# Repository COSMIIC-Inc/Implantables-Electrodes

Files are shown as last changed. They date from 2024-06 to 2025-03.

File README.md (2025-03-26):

# Implantables-Electrodes Read Me

## Contents
This repository is home to the 3D CAD design files of the electrodes in the COSMIIC System.
Further documentation is available at **[docs.cosmiic.org/Implantables/Electrodes](https://docs.cosmiic.org/Implantables/Electrodes)**

## Licensing
Hardware-related files are licensed to open source users by COSMIIC under the CERN Open Hardware License - Permissive - v2 (CERN-OHL-P-2.0). Refer to the **[license text](https://ohwr.org/cern_ohl_p_v2.txt)** (also embedded in the repository as **LICENSE.txt**) and **[user guide](https://ohwr.org/project/cernohl/-/wikis/uploads/8a6b5d01f71c207c49493e4d114d61e6/cern_ohl_p_v2_howto.pdf)** to understand your permissions.

Hardware-related files includes, but is not limited to...

- Mechanical Design
    - 3D CAD Files (parts and assemblies, multiple file types)
    - Mechanical Drawings (parts and assemblies, mulitple file types)
- PCB Design
    - Fabrication (Gerber and Drill files)
    - Assembly (Pick and Place, BOM)
    - Archive (Schematics, multiple file types)

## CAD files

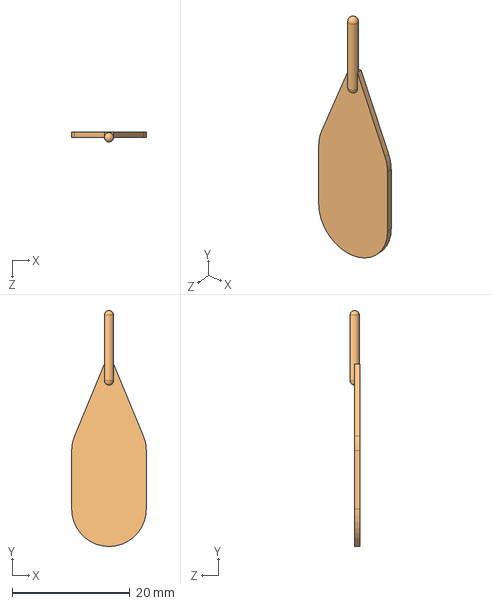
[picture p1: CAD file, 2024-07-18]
Mechanical Design CAD Files/Epimysial MES Electrode Cable/SolidWorks Native Files/NNP-DWG-145-008-000 SA, EPI, MES, Electrode.SLDASM
12.7 x 40.1 x 1.68 mm
NNP-DWG-140-015-000 Electrode, EPI, MES, Silicone Molding Blank
NNP-DWG-140-014-000 Electrode, EPI, Disk x 2

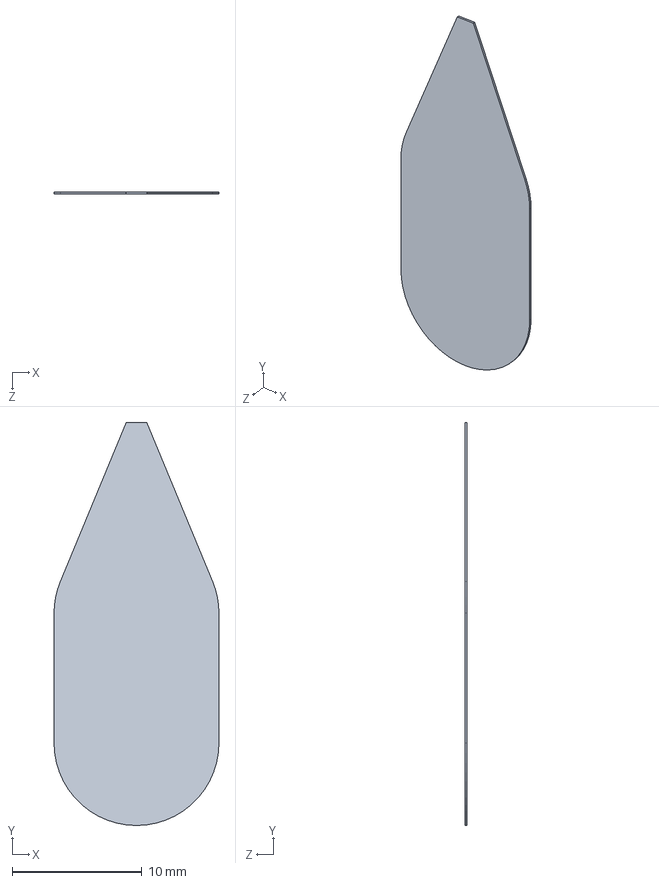
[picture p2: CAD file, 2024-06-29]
Mechanical Design CAD Files/Epimysial MES Electrode Cable/STEP Files/NNP-DWG-140-016-000 Electrode, EPI, MES, Reinforcing Mesh.STEP
12.7 x 31.0 x 0.178 mm

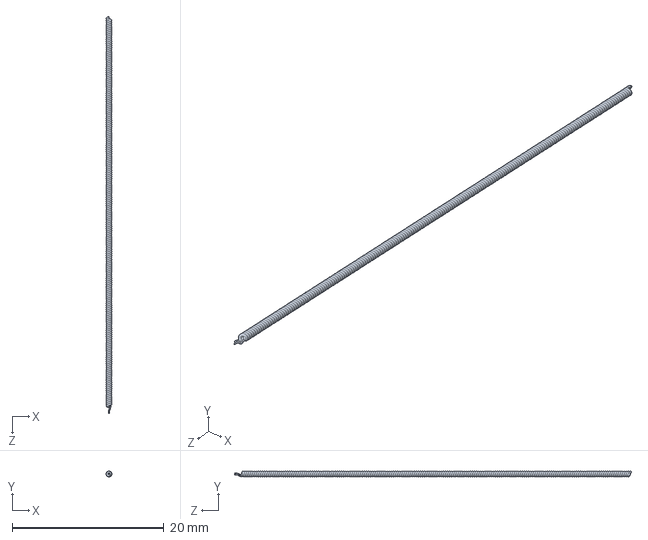
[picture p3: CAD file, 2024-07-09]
Mechanical Design CAD Files/IM Stim Electrode Cable/SolidWorks Native Files/NNP-DWG-140-011-001 Filar, SS, Red-Clear.SLDPRT
0.753 x 0.753 x 52.3 mm

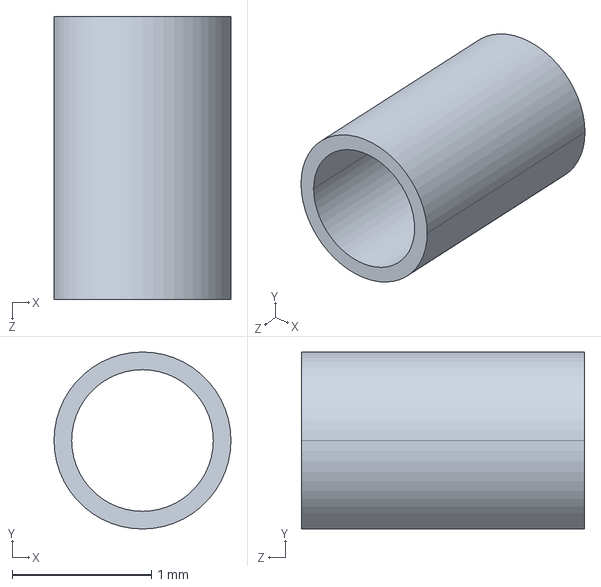
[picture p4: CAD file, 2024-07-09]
Mechanical Design CAD Files/IM Stim Electrode Cable/STEP Files/NNP-DWG-140-019-002 Electrode, IM, Stim, Coil.STEP
1.27 x 1.27 x 2.03 mm

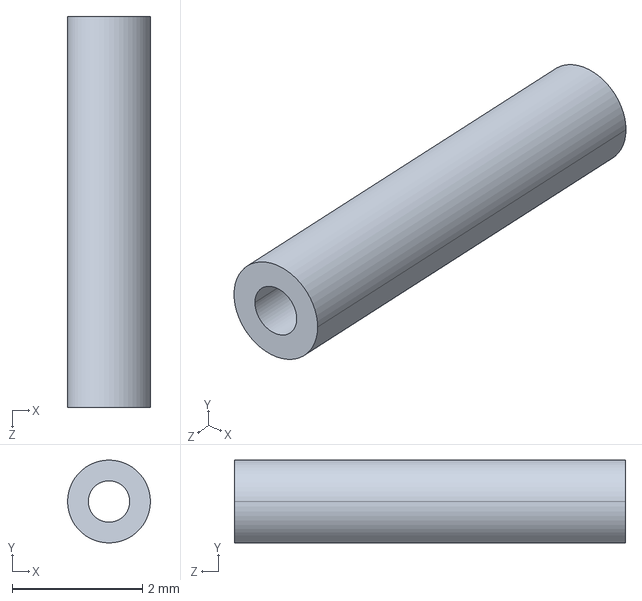
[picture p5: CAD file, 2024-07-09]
Mechanical Design CAD Files/IM-MES Electrode Cable/STEP Files/NNP-DWG-140-018-000 Electrode, IM, Silicone Tubing Spacer.STEP
1.27 x 1.27 x 5.99 mm

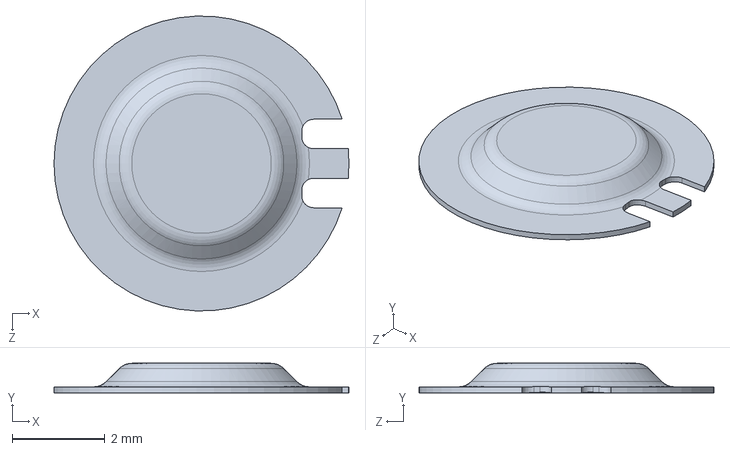
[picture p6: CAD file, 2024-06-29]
Mechanical Design CAD Files/Epimysial MES Electrode Cable/SolidWorks Native Files/NNP-DWG-140-014-000 Electrode, EPI, Disk.SLDPRT
6.35 x 0.635 x 6.35 mm

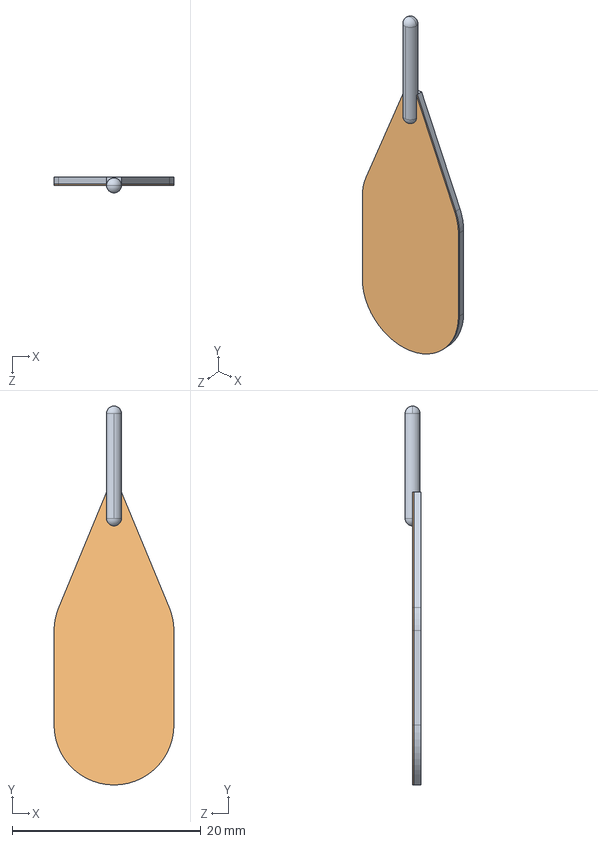
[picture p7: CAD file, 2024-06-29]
Mechanical Design CAD Files/Epimysial MES Electrode Cable/STEP Files/NNP-DWG-145-008-000 SA, EPI, MES, Electrode.STEP
12.7 x 40.1 x 1.68 mm
NNP-DWG-140-015-000 Electrode, EPI, MES, Silicone Molding Blank
NNP-DWG-140-016-000 Electrode, EPI, MES, Reinforcing Mesh
NNP-DWG-140-014-000 Electrode, EPI, Disk x 2

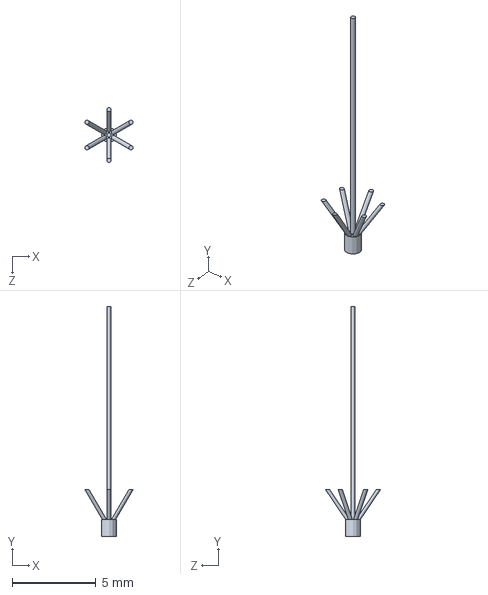
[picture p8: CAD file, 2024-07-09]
Mechanical Design CAD Files/IM Stim Electrode Cable/SolidWorks Native Files/NNP-DWG-140-013-002 Electrode, IM, Stim, Prolene Barb.SLDPRT
2.87 x 13.7 x 3.28 mm

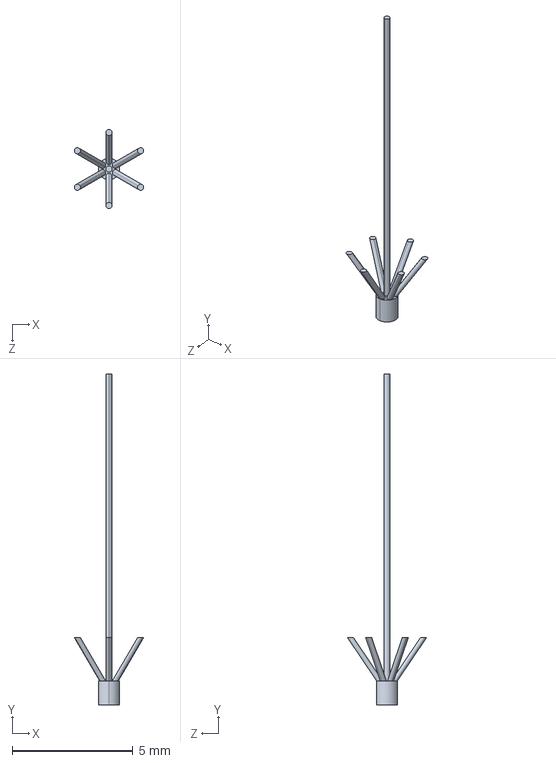
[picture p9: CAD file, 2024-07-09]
Mechanical Design CAD Files/IM Stim Electrode Cable/STEP Files/NNP-DWG-140-013-002 Electrode, IM, Stim, Prolene Barb.STEP
2.87 x 13.7 x 3.28 mm

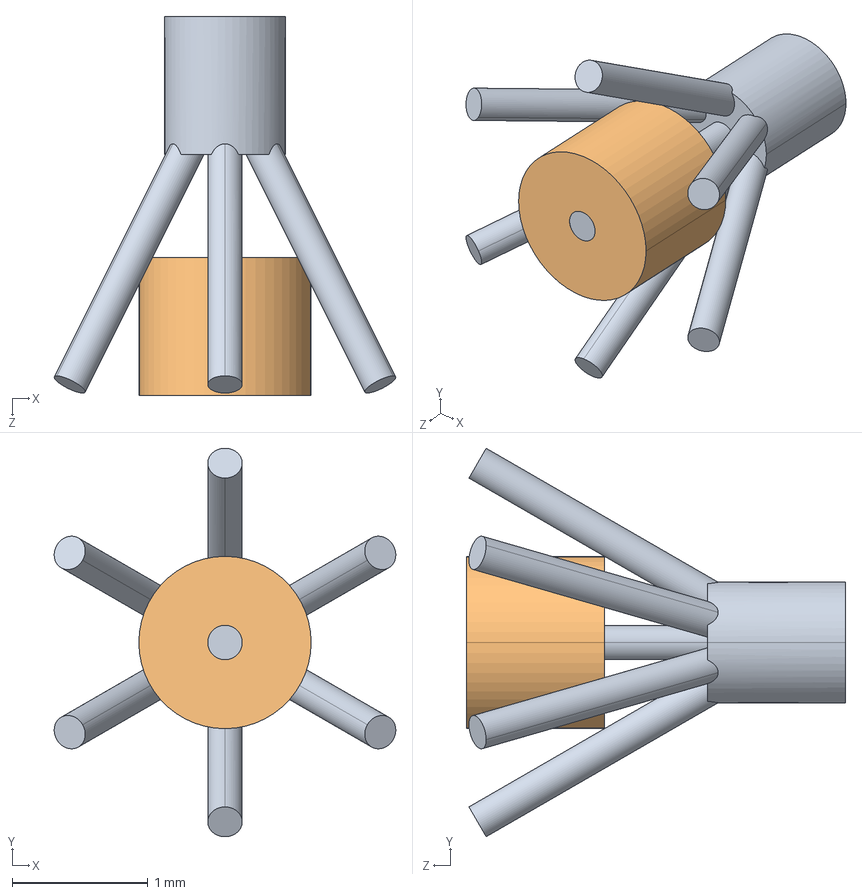
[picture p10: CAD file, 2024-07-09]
Mechanical Design CAD Files/IM-MES Electrode Cable/STEP Files/NNP-DWG-145-010-000 SA, Electrode, IM, Barb Tip.STEP
2.52 x 2.86 x 2.79 mm
NNP-DWG-140-013-000 Electrode, IM, Prolene Barb
NNP-DWG-140-017-000 Electrode, IM, Silicone Tube Extension

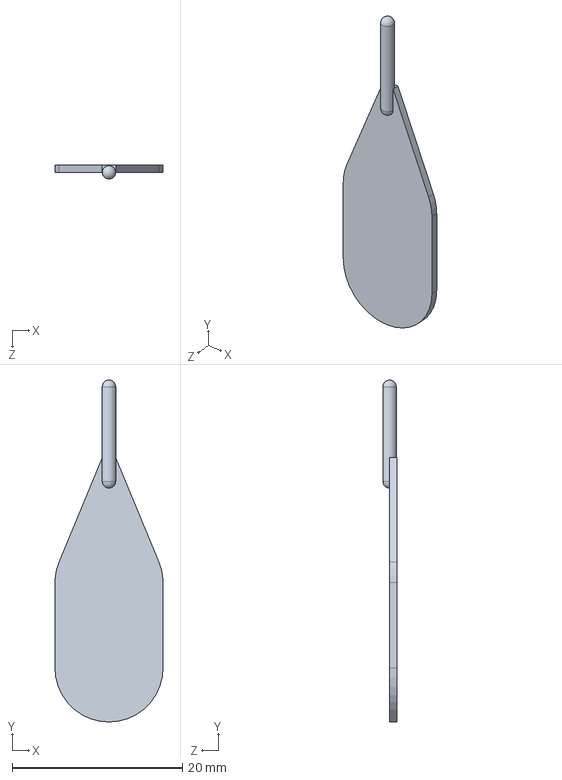
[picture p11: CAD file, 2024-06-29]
Mechanical Design CAD Files/Epimysial MES Electrode Cable/SolidWorks Native Files/NNP-DWG-140-015-000 Electrode, EPI, MES, Silicone Molding Blank.SLDPRT
12.7 x 40.1 x 1.68 mm

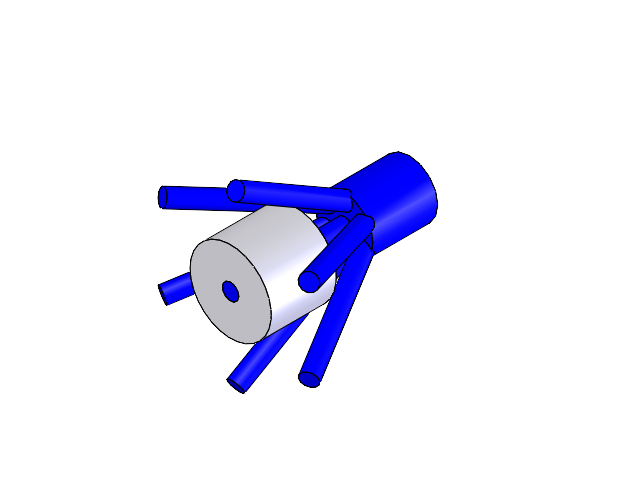
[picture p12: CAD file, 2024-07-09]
Mechanical Design CAD Files/IM-MES Electrode Cable/SolidWorks Native Files/NNP-DWG-145-010-000 SA, Electrode, IM, Barb Tip.SLDASM
NNP-DWG-140-013-001 Electrode, IM, MES, Prolene Barb
NNP-DWG-140-017-000 Electrode, IM, Silicone Tube Extension

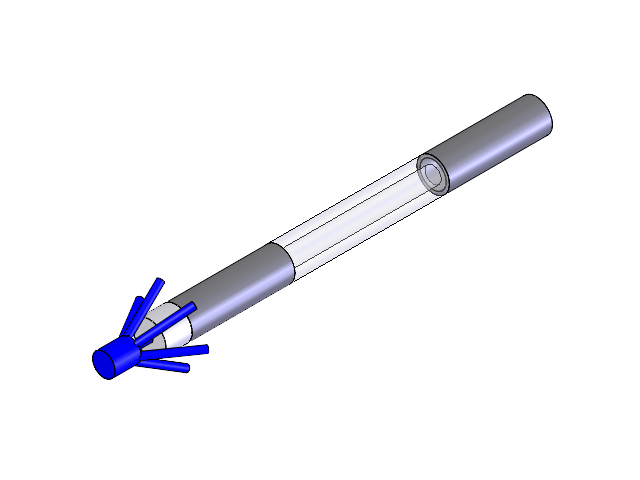
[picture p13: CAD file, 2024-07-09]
Mechanical Design CAD Files/IM-MES Electrode Cable/SolidWorks Native Files/NNP-DWG-145-011-000 SA, Electrode, IM, MES.SLDASM
NNP-DWG-140-019-001 Electrode, IM, MES, Coil x 2
NNP-DWG-140-013-001 Electrode, IM, MES, Prolene Barb
NNP-DWG-140-017-000 Electrode, IM, Silicone Tube Extension
NNP-DWG-140-018-000 Electrode, IM, Silicone Tubing Spacer

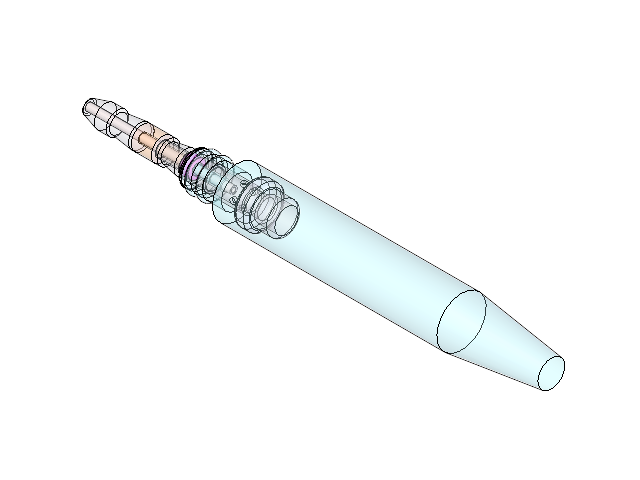
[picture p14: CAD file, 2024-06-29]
Mechanical Design CAD Files/Epimysial MES Electrode Cable/STEP Files/NNP-DWG-145-001-000 Interconnect.SLDASM
NNP-DWG-140-004-000 Interconnect, Front-Rear Insulator
NNP-DWG-140-002-001 Interconnect, Rear Contact, SS
NNP-DWG-140-007-001 Interconnect, Front Weld Sleeve, SS
NNP-DWG-140-008-001 Interconnect, Crimp Weld Reducer, SS
NNP-DWG-140-009-000 Interconnect, Silicone Over Mold
NNP-DWG-140-003-001 Interconnect, NNP Center Conductor, SS
NNP-DWG-140-006-000 Interconnect, Washer
NNP-DWG-140-005-001 Interconnect, Strain Relief, SS
NNP-DWG-140-001-001 Interconnect, Front Contact, SS

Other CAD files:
Mechanical Design CAD Files/IM-MES Electrode Cable/SolidWorks Native Files/NNP-DWG-145-001-000 Interconnect.SLDASM
Mechanical Design CAD Files/IM Stim Electrode Cable/SolidWorks Native Files/NNP-DWG-145-012-000 SA, Electrode, IM, Stim.SLDASM
Mechanical Design CAD Files/IM Stim Electrode Cable/SolidWorks Native Files/NNP-DWG-145-001-000 Interconnect.SLDASM
Mechanical Design CAD Files/IM-MES Electrode Cable/SolidWorks Native Files/NNP-DWG-145-007-003 SA, Cable Body, Insulated SS Filars, Green-Clear.SLDASM
Mechanical Design CAD Files/Epimysial MES Electrode Cable/STEP Files/NNP-DWG-140-014-000 Electrode, EPI, Disk.STEP
Mechanical Design CAD Files/Epimysial MES Electrode Cable/STEP Files/NNP-DWG-140-015-000 Electrode, EPI, MES, Silicone Molding Blank.STEP
Mechanical Design CAD Files/Epimysial MES Electrode Cable/SolidWorks Native Files/NNP-DWG-140-014-000 Electrode, EPI, Disk.SLDDRW
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

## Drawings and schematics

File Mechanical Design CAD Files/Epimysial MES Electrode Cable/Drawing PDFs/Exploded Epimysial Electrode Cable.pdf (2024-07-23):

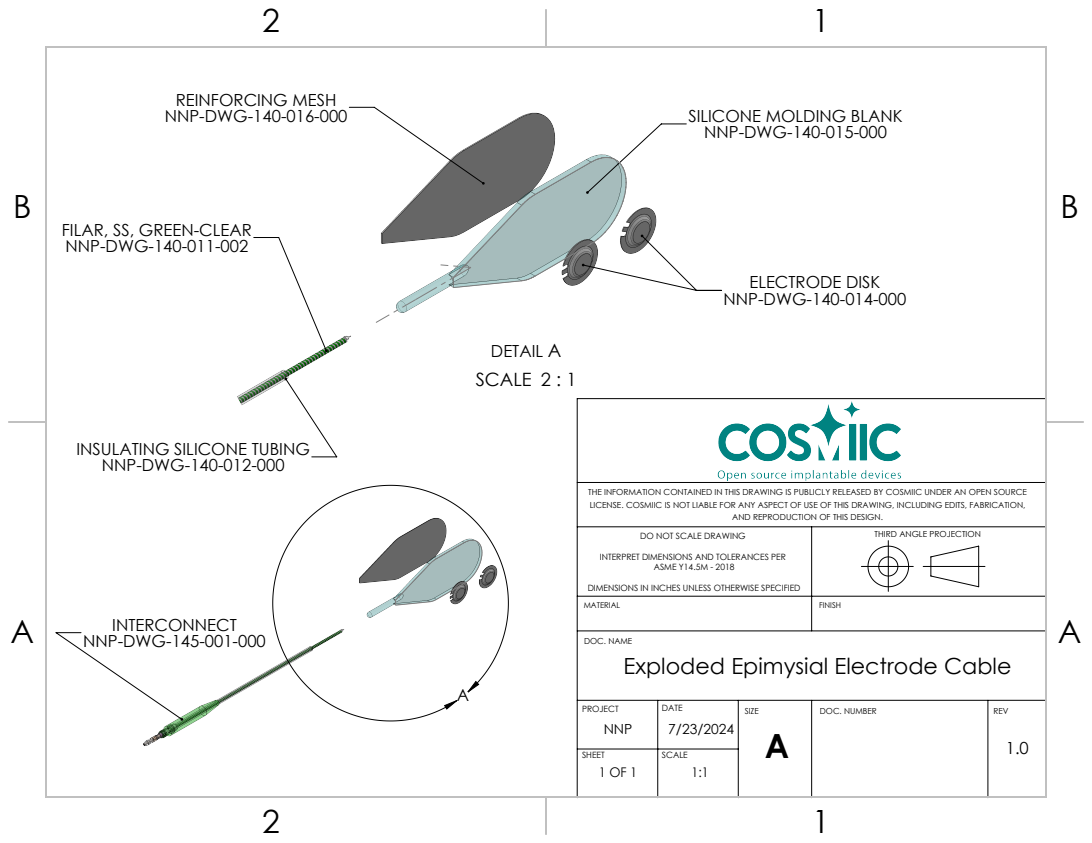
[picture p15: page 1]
DETAIL A SCALE 2 : 1; ELECTRODE DISK; REINFORCING MESH; ASME Y14.5M - 2018; DOC. NAME; DOC. NUMBER; REV

SILICONE MOLDING BLANK
NNP-DWG-140-015-000

FILAR, SS, GREEN-CLEAR
NNP-DWG-140-011-002

INSULATING SILICONE TUBING
NNP-DWG-140-012-000

THE INFORMATION CONTAINED IN THIS DRAWING IS PUBLICLY RELEASED BY COSMIIC UNDER AN OPEN SOURCE
LICENSE. COSMIIC IS NOT LIABLE FOR ANY ASPECT OF USE OF THIS DRAWING, INCLUDING EDITS, FABRICATION,

AND REPRODUCTION OF THIS DESIGN.

DO NOT SCALE DRAWING

THIRD ANGLE PROJECTION

INTERPRET DIMENSIONS AND TOLERANCES PER

DIMENSIONS IN INCHES UNLESS OTHERWISE SPECIFIED
Exploded Epimysial Electrode Cable

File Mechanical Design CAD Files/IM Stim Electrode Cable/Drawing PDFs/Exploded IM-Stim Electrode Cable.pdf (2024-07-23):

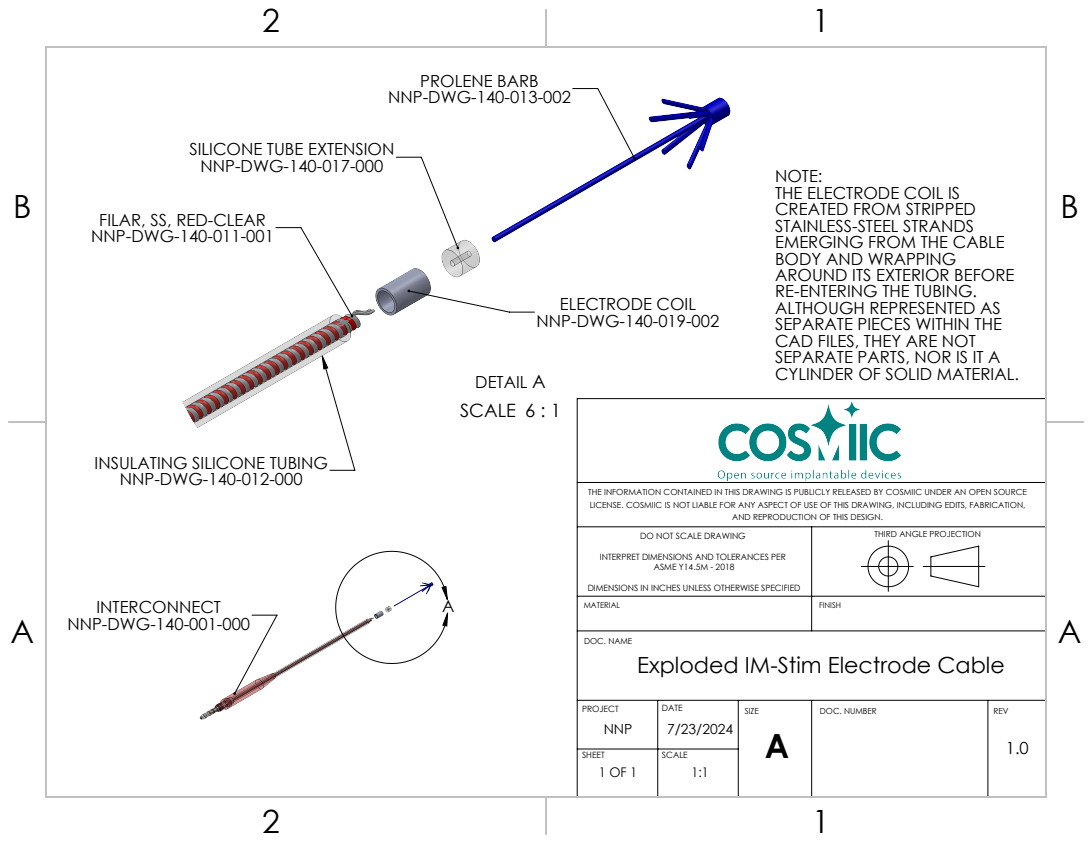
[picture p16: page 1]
DETAIL A SCALE 6 : 1; PROLENE BARB; ELECTRODE COIL; ASME Y14.5M - 2018; DOC. NAME; DOC. NUMBER; REV

SILICONE TUBE EXTENSION
NNP-DWG-140-017-000

NOTE:
THE ELECTRODE COIL IS
CREATED FROM STRIPPED
STAINLESS-STEEL STRANDS
EMERGING FROM THE CABLE
BODY AND WRAPPING
AROUND ITS EXTERIOR BEFORE
RE-ENTERING THE TUBING.
ALTHOUGH REPRESENTED AS
SEPARATE PIECES WITHIN THE
CAD FILES, THEY ARE NOT
SEPARATE PARTS, NOR IS IT A
CYLINDER OF SOLID MATERIAL.

FILAR, SS, RED-CLEAR
NNP-DWG-140-011-001

INSULATING SILICONE TUBING
NNP-DWG-140-012-000

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

AND REPRODUCTION OF THIS DESIGN.

DO NOT SCALE DRAWING

THIRD ANGLE PROJECTION

INTERPRET DIMENSIONS AND TOLERANCES PER

DIMENSIONS IN INCHES UNLESS OTHERWISE SPECIFIED
Exploded IM-Stim Electrode Cable

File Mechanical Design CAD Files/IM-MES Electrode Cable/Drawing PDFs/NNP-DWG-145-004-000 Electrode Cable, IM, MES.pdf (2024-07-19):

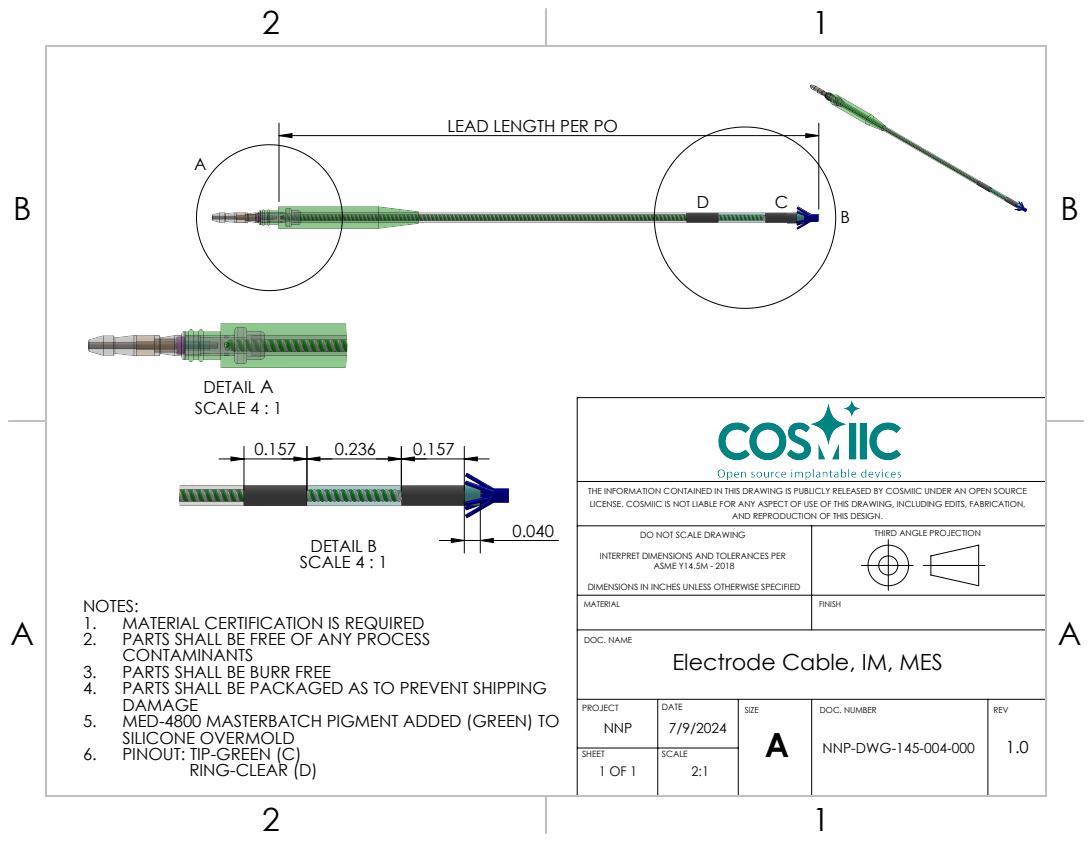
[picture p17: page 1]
DETAIL A SCALE 4 : 1; DETAIL B SCALE 4 : 1; RING-CLEAR (D); ASME Y14.5M - 2018; DOC. NAME; DOC. NUMBER; REV

LEAD LENGTH PER PO

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

AND REPRODUCTION OF THIS DESIGN.

DO NOT SCALE DRAWING

THIRD ANGLE PROJECTION

INTERPRET DIMENSIONS AND TOLERANCES PER

DIMENSIONS IN INCHES UNLESS OTHERWISE SPECIFIED
Electrode Cable, IM, MES

NOTES:
1. MATERIAL CERTIFICATION IS REQUIRED

2. PARTS SHALL BE FREE OF ANY PROCESS
CONTAMINANTS
3. PARTS SHALL BE BURR FREE
4. PARTS SHALL BE PACKAGED AS TO PREVENT SHIPPING
DAMAGE
5. MED-4800 MASTERBATCH PIGMENT ADDED (GREEN) TO
SILICONE OVERMOLD
6. PINOUT: TIP-GREEN (C)

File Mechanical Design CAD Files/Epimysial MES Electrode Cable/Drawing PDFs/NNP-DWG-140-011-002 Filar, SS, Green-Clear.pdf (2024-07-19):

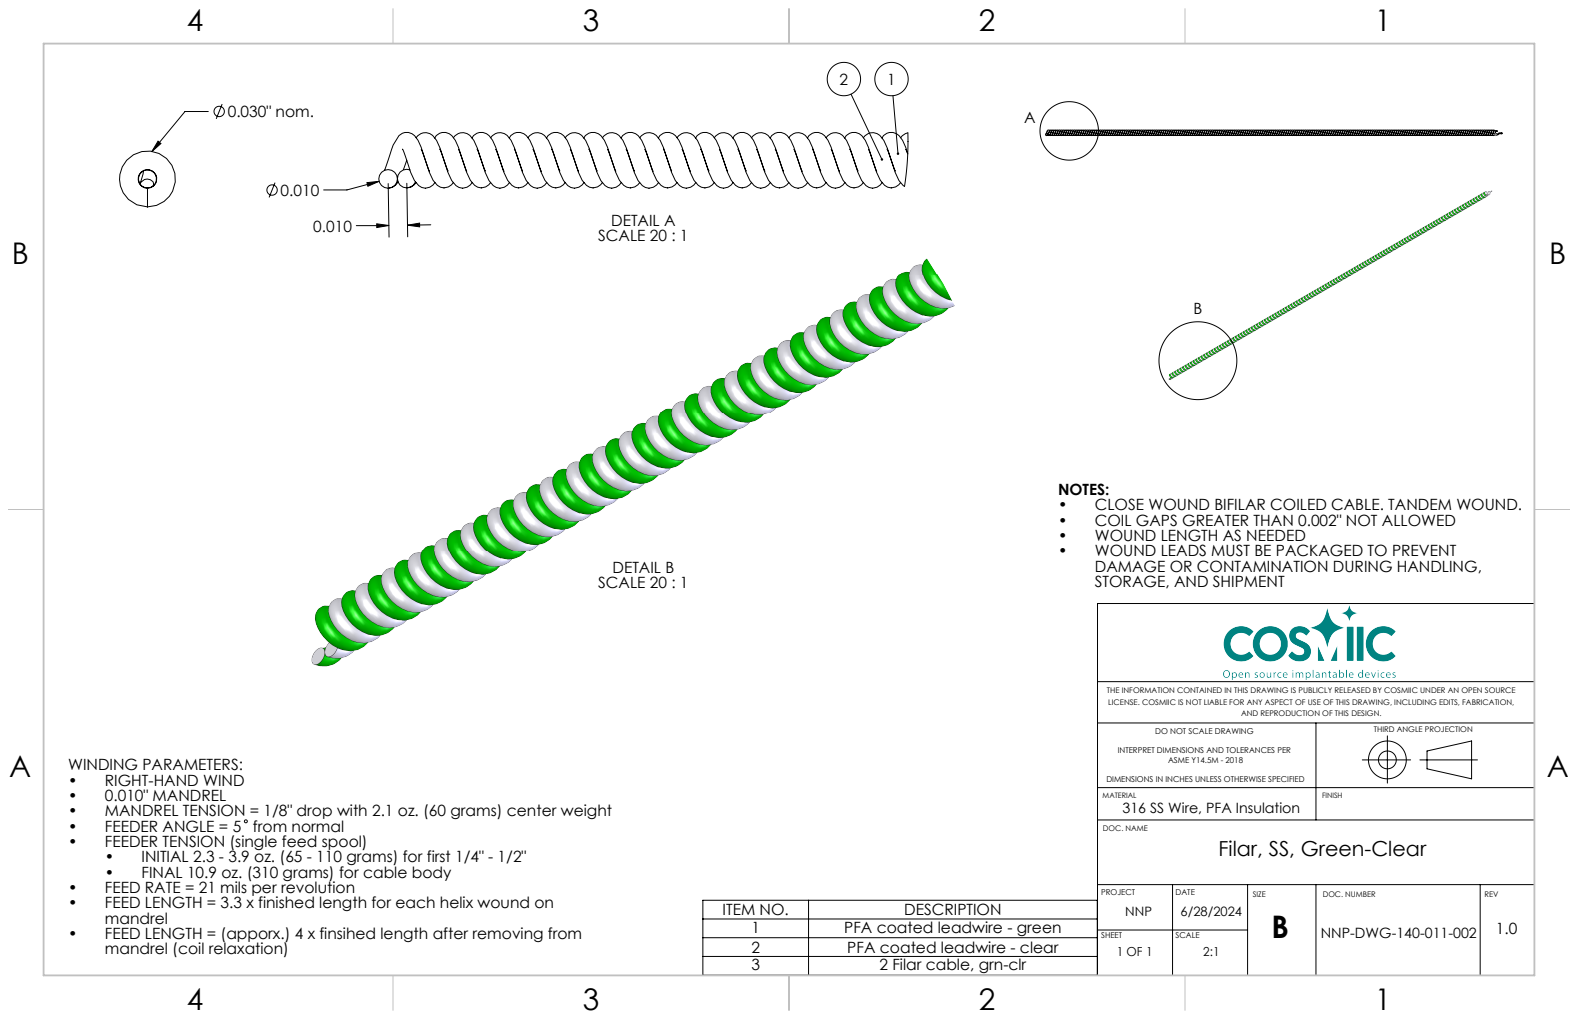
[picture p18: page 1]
DETAIL B SCALE 20 : 1; 0.030" nom.; DETAIL A SCALE 20 : 1; WINDING PARAMETERS:; RIGHT-HAND WIND •; 0.010" MANDREL •; MANDREL TENSION = 1/8" drop with 2.1 oz. (60 grams) center weight •; FEEDER ANGLE = 5 from normal •; FEEDER TENSION (single feed spool); INITIAL 2.3 - 3.9 oz. (65 - 110 grams) for first 1/4" - 1/2" •; FINAL 10.9 oz. (310 grams) for cable body •; FEED RATE = 21 mils per revolution •; FEED LENGTH = 3.3 x finished length for each helix wound on; mandrel •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

DAMAGE OR CONTAMINATION DURING HANDLING,
STORAGE, AND SHIPMENT

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

AND REPRODUCTION OF THIS DESIGN.

DO NOT SCALE DRAWING

THIRD ANGLE PROJECTION

INTERPRET DIMENSIONS AND TOLERANCES PER

DIMENSIONS IN INCHES UNLESS OTHERWISE SPECIFIED
316 SS Wire, PFA Insulation

Filar, SS, Green-Clear
NNP-DWG-140-011-002

ITEM NO. | DESCRIPTION
1 | PFA coated leadwire - green
2 | PFA coated leadwire - clear
3 | 2 Filar cable, grn-clr

mandrel (coil relaxation)

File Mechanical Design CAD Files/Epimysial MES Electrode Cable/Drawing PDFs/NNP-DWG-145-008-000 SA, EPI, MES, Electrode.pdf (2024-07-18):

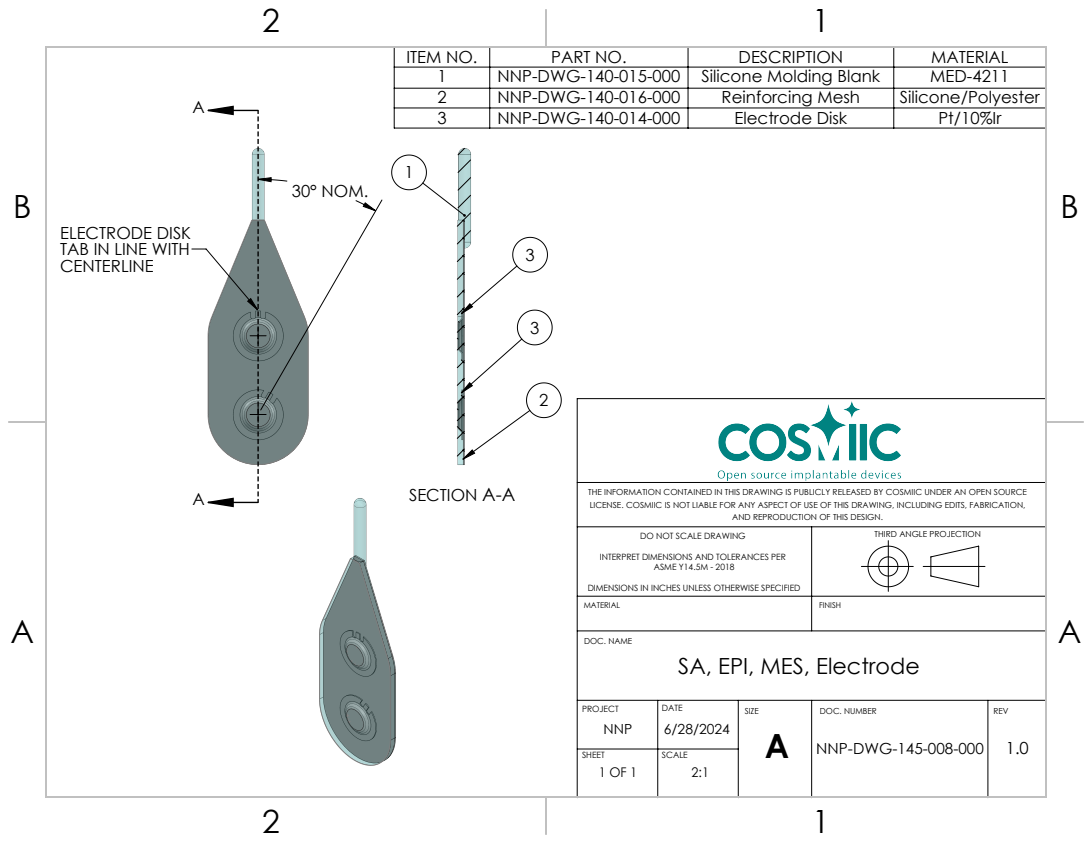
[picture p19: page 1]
30° NOM.; SECTION A-A; ASME Y14.5M - 2018; DOC. NAME; DOC. NUMBER; REV

ITEM NO. | PART NO. | DESCRIPTION | MATERIAL
1 | NNP-DWG-140-015-000 | Silicone Molding Blank | MED-4211
2 | NNP-DWG-140-016-000 | Reinforcing Mesh | Silicone/Polyester
3 | NNP-DWG-140-014-000 | Electrode Disk | Pt/10%Ir

ELECTRODE DISK
TAB IN LINE WITH
CENTERLINE

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

AND REPRODUCTION OF THIS DESIGN.

DO NOT SCALE DRAWING

THIRD ANGLE PROJECTION

INTERPRET DIMENSIONS AND TOLERANCES PER

DIMENSIONS IN INCHES UNLESS OTHERWISE SPECIFIED

SA, EPI, MES, Electrode
NNP-DWG-145-008-000 1.0

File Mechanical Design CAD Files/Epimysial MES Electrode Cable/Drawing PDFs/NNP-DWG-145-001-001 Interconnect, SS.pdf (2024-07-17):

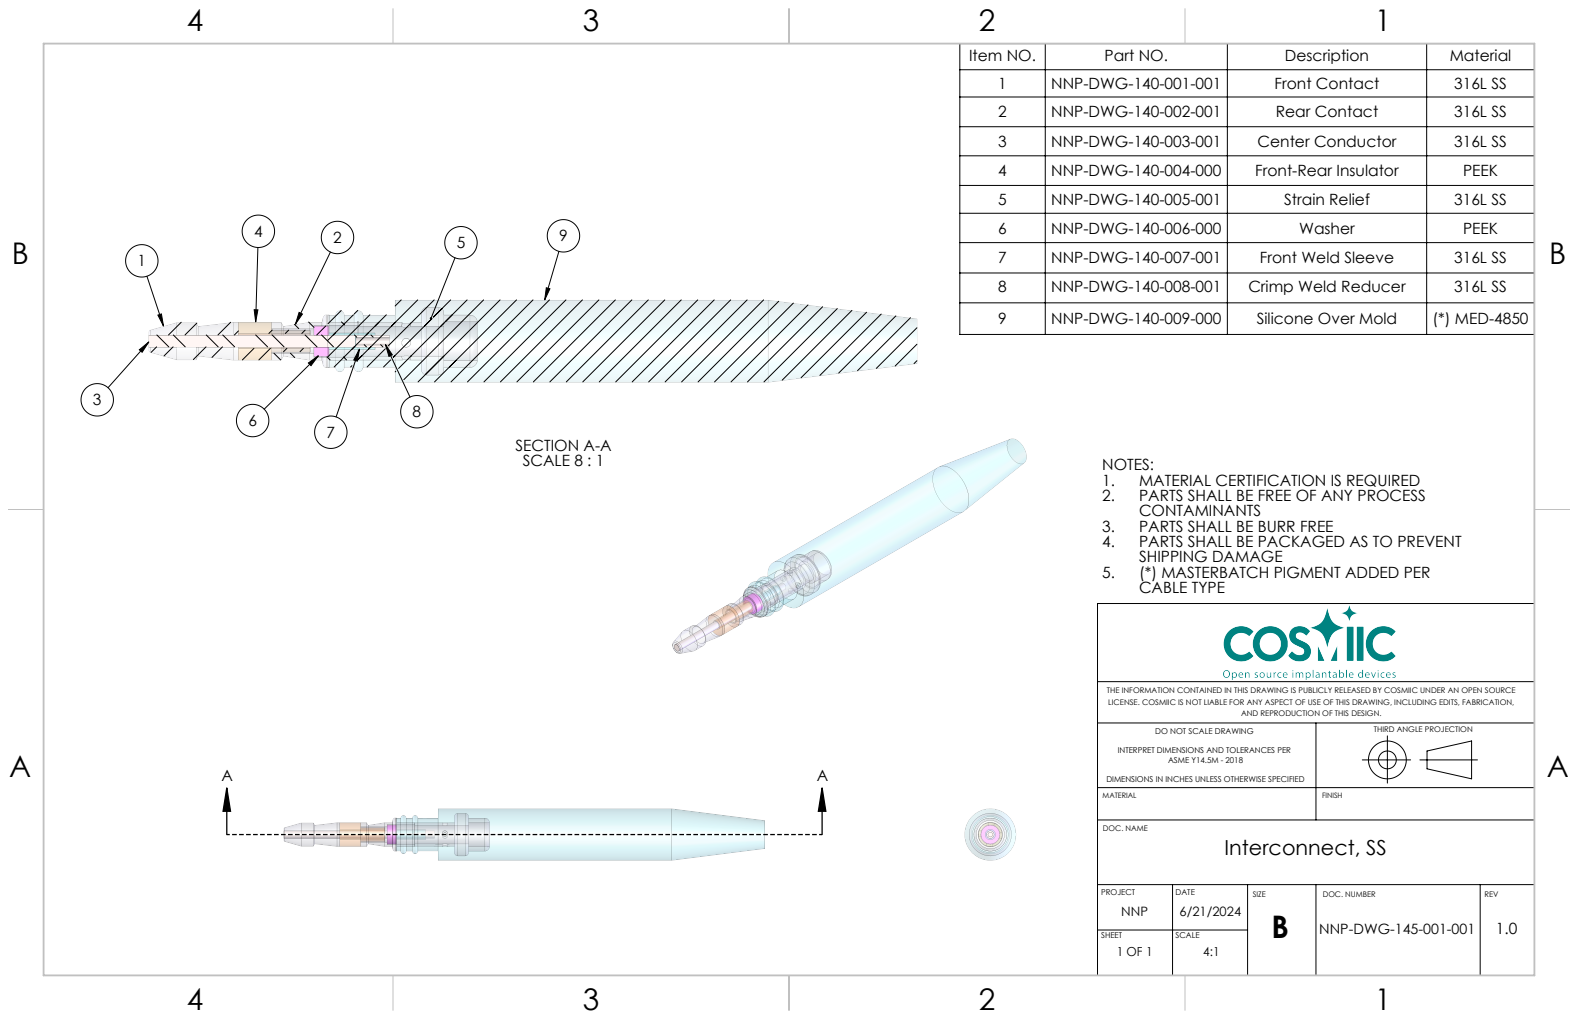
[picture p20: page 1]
SECTION A-A; SCALE 8 : 1 9; Item NO.; Part NO.; Description; Material 1; NNP-DWG-140-001-001; Front Contact; NNP-DWG-140-002-001; Rear Contact; NNP-DWG-140-003-001; Center Conductor; NNP-DWG-140-004-000; Front-Rear Insulator; PEEK 5; NNP-DWG-140-005-001; Strain Relief; NNP-DWG-140-006-000; Washer; PEEK 7; NNP-DWG-140-007-001; Front Weld Sleeve; NNP-DWG-140-008-001; Crimp Weld Reducer; NNP-DWG-140-009-000; Silicone Over Mold; (*) MED-4850; DOC. NUMBER; REV; DOC. NAME; ASME Y14.5M - 2018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

NOTES:
1. MATERIAL CERTIFICATION IS REQUIRED
2. PARTS SHALL BE FREE OF ANY PROCESS
CONTAMINANTS
3. PARTS SHALL BE BURR FREE
4. PARTS SHALL BE PACKAGED AS TO PREVENT
SHIPPING DAMAGE
5. (*) MASTERBATCH PIGMENT ADDED PER
CABLE TYPE

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

AND REPRODUCTION OF THIS DESIGN.

DO NOT SCALE DRAWING

THIRD ANGLE PROJECTION

INTERPRET DIMENSIONS AND TOLERANCES PER

DIMENSIONS IN INCHES UNLESS OTHERWISE SPECIFIED

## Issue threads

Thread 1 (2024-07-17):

Verification Protocols rework - electrodes

crexroth, 2024-07-17:
Could you please change these things...
* Requirements addressed should reference that tag for the ID from the corresponding NNP-REQ document?
* The Revision History should be updated to have your name as author and date. Jenna put "First version of document" for summary of changes.
* Remove the approval history section from the end of document and table of contents.
You can choose if you want to port things over into the updated template I made last month (automatic bullet points and table of contents) or if you just want to work with what you already have. Whatever is faster.

Jenna just made these same changes for her Network Cable test reports.

I uploaded the reqs document

dr-mh, 2024-07-17:
All done:)

Closed 2024-07-17.

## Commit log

2024-06-29 Add Files
    Adding pdfs, SW, and step files for epimysial MES electrode
    [NNP-DWG-140-011-002 Filar, SS, Green-Clear.SLDDRW, NNP-DWG-140-011-002 Filar, SS, Green-Clear.SLDPRT, NNP-DWG-140-012-000 Cable, Insulating Silicone Tubing.SLD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]
2024-07-09 Adding IM-MES Files
    [NNP-DWG-140-011-002 Filar, SS, Green-Clear.SLDDRW, NNP-DWG-140-011-002 Filar, SS, Green-Clear.SLDPRT, NNP-DWG-140-012-000 Cable, Insulating Silicone Tubing.SLD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]
2024-07-09 Update IM-MES cable drawing
    Added "length per po" note
    [NNP-DWG-145-004-000 Electrode Cable, IM, MES.SLDDRW]
2024-07-09 Updating Name of File
    from "IM, COIL" to "IM, MES, COIL"
    [NNP-DWG-140-019-000 Electrode, IM, Coil.SLDDRW, NNP-DWG-140-019-000 Electrode, IM, MES, Coil.SLDDRW, NNP-DWG-140-019-000 Electrode, IM, MES, Coil.SLDPRT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]
2024-07-09 Update part number
    -000 to -001
    [NNP-DWG-140-019-000 Electrode, IM, MES, Coil.SLDDRW, NNP-DWG-140-019-001 Electrode, IM, MES, Coil.SLDDRW, NNP-DWG-140-019-001 Electrode, IM, MES, Coil.SLDPRT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]
2024-07-09 Update name and part number
    Added "MES", -000 to -001
    [NNP-DWG-140-013-000 Electrode, IM, Prolene Barb.SLDDRW, NNP-DWG-140-013-001 Electrode, IM, MES, Prolene Barb.SLDDRW, NNP-DWG-140-013-001 Electrode, IM, MES, Pr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]
2024-07-09 Adding IM-Stim Files
    [NNP-DWG-140-011-001 Filar, SS, Red-Clear.SLDDRW, NNP-DWG-140-011-001 Filar, SS, Red-Clear.SLDPRT, NNP-DWG-140-012-000 Cable, Insulating Silicone Tubing.SLDDRW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]
2024-07-09 Swap step and native file
    [NNP-DWG-145-001-000 Interconnect.SLDASM, NNP-DWG-145-001-000 Interconnect.STEP]
2024-07-09 Updating native files
    Had to update and resave due to some component name changes
    [NNP-DWG-145-010-000 SA, Electrode, IM, Barb Tip.SLDASM, NNP-DWG-145-010-000 SA, Electrode, IM, Barb Tip.SLDDRW, NNP-DWG-145-011-000 SA, Electrode, IM, MES.SLDA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]
2024-07-10 Adding Files
    Added insulated filar file for red/clear cable
2024-07-10 Update Electrode Cable Drawing
    Added notes, dimensions
    [NNP-DWG-145-005-000 Electrode Cable, IM, Stim.SLDDRW]
2024-07-10 Updating EPI/MES electrode cable drawing
    Added notes; removed MES-Interconnect files due to not necessary and to match other electrodes. Files still exist locally if needed in the future
    [NNP-DWG-145-003-000 Electrode Cable, EPI, MES.SLDDRW, NNP-DWG-145-009-000 SA, EPI, MES-Interconnect.SLDDRW]
2024-07-12 Adding electrode cable test protocols
2024-07-17 Added masterbatch pigment note
    [NNP-DWG-145-001-001 Interconnect, SS.SLDDRW]
2024-07-18 Updated drawing note
    [NNP-DWG-145-008-000 SA, EPI, MES, Electrode.SLDASM, NNP-DWG-145-008-000 SA, EPI, MES, Electrode.SLDDRW]
2024-07-19 Update material note
2024-07-19 Electrode Cable Testing V1
    First versions of network cable testing.
2024-07-22 Removing unnecessary drawings
    After discussing with Brian, I am removing drawings of individual parts and some sub-assemblies that do not represent the manufacturing process instructions. The SolidWorks part files are still in th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
    [NNP-DWG-140-017-000 Electrode, IM, Silicone Tube Extension.SLDDRW, NNP-DWG-140-018-000 Electrode, IM, Silicone Tubing Spacer.SLDDRW, NNP-DWG-140-019-001 Electr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]
2024-07-23 Removed unnecessary drawings
    [NNP-DWG-145-011-000 SA, Electrode, IM, MES.SLDDRW]
2025-07-31 First test of hornet cad manifest
